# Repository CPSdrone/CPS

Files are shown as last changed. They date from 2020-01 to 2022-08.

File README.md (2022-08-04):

# CPS [Custom Printed Submarine]  CPSlogo

Is a project started by Filip Buława, Piotr Domanowski and Marcin Hnat. 
It is about creating a functional product of a innovative submarine, primarily with live streaming from camera in the drone. 
Project is based on 3D printing process, which allows developing various solutions for the form of a drone.

To learn more, find us on
* [Instagram](https://instagram.com/cpsdrone)
* [Facebook](https://facebook.com/cpsdrone)
* [YouTube](https://www.youtube.com/channel/UCqbdxbvG6cqnh_S_RcGnWWg)

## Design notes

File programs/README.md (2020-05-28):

# Welcome to our program storage.
## How to use our programs:

At the moment all of our programs use *Arduino IDE*, so 
1. make sure you installed this program
1. copy all of the libraries to the folder in the directory of your Arduino program, that is `Arduino/libraries`

Generally, the latest programs are the best.
Right now, if you want to use basic CPS code, use version 5.1.
For CPS M, probably `5.0/first_OSD_and_cleanup` is the best.

> Note: **Don't** look at the 1.0 - 2.0 so we won't feel ashamed.

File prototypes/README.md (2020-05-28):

#Welcome to our prototypes storage
Choose whether you want to explore **CPS** or **CPS M**

To learn more about each of these drones, visit our [Facebook](facebook.com/cpsdrone) or [YouTube](https://www.youtube.com/channel/UCqbdxbvG6cqnh_S_RcGnWWg) accounts
Shortly, **CPS** is:
* the basing drone for underwater exploration using only your live camera. More compact, less effort, fun build.
* the modular drone for more complex underwater exploration. 4 slots for any desired modules [like water sampler, manipulator, pH meter]. Still compact form, more effort, super fun especially with modules.

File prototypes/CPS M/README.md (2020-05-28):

# CPS M  prototypes
Along the way, we already had few prototypes of **CPS M**.

Generally, the latest prototype is the best.
In the folders you'll find models, list of materials and electronic diagrams.

Choose wisely

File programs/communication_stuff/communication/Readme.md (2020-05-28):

# Communication stuff
Here you can find code facilitating communication from outside to the drone and between individual components of the drone itself. For now, these are:
* raspberry pi 3
* Arduino mega 2560
the above are communicating by SPI. Communication with outside will be through WiFi.

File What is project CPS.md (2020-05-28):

CPSlogo
# CPS [Custom Printed Submarine]

 is an open-source project started by Filip Buława, Piotr Domanowski and Marcin Hnat. 
 It is about creating a functional product of a innovative submarine, primarily with live streaming from camera in the drone. 
 Project is based on 3D printing process, which allows developing various solutions for the form of a drone. 
Since the project is open-source, it will be easy for interested individuals to modify available models and programs and share with other people, who can eventually print it on their own 3D printers.

To learn more, find us on
* [Instagram](instagram.com/cpsdrone)
* [Facebook](facebook.com/cpsdrone)
* [YouTube](https://www.youtube.com/channel/UCqbdxbvG6cqnh_S_RcGnWWg)

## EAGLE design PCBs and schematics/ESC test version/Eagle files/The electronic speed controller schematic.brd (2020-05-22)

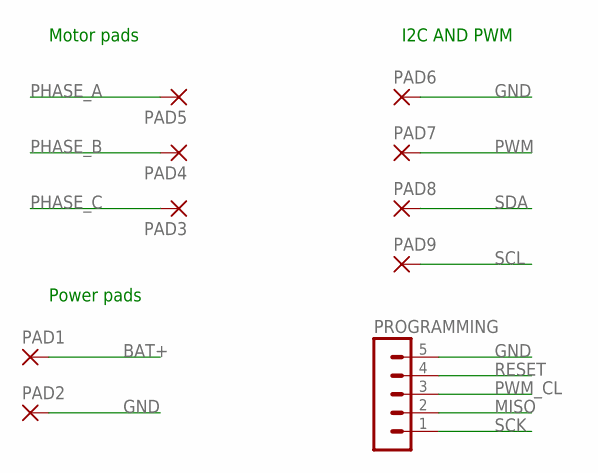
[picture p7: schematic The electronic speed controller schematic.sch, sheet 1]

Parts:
PAD1, PAD2, PAD3, PAD4, PAD5: SMD5; SMD2,54-5,08
PAD6, PAD7, PAD8, PAD9: SMD2; SMD1,27-2,54
PROGRAMMING: MA05-1

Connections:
BAT+: PAD1.1; also elsewhere on the board
GND: PAD2.1, PAD6.1, PROGRAMMING.5; also elsewhere on the board
MISO: PROGRAMMING.2; also elsewhere on the board
PHASE_A: PAD5.1; also elsewhere on the board
PHASE_B: PAD4.1; also elsewhere on the board
PHASE_C: PAD3.1; also elsewhere on the board
PWM: PAD7.1; also elsewhere on the board
PWM_CL: PROGRAMMING.3; also elsewhere on the board
RESET: PROGRAMMING.4; also elsewhere on the board
SCK: PROGRAMMING.1; also elsewhere on the board
SCL: PAD9.1; also elsewhere on the board
SDA: PAD8.1; also elsewhere on the board

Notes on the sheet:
Power pads
Motor pads
I2C AND PWM

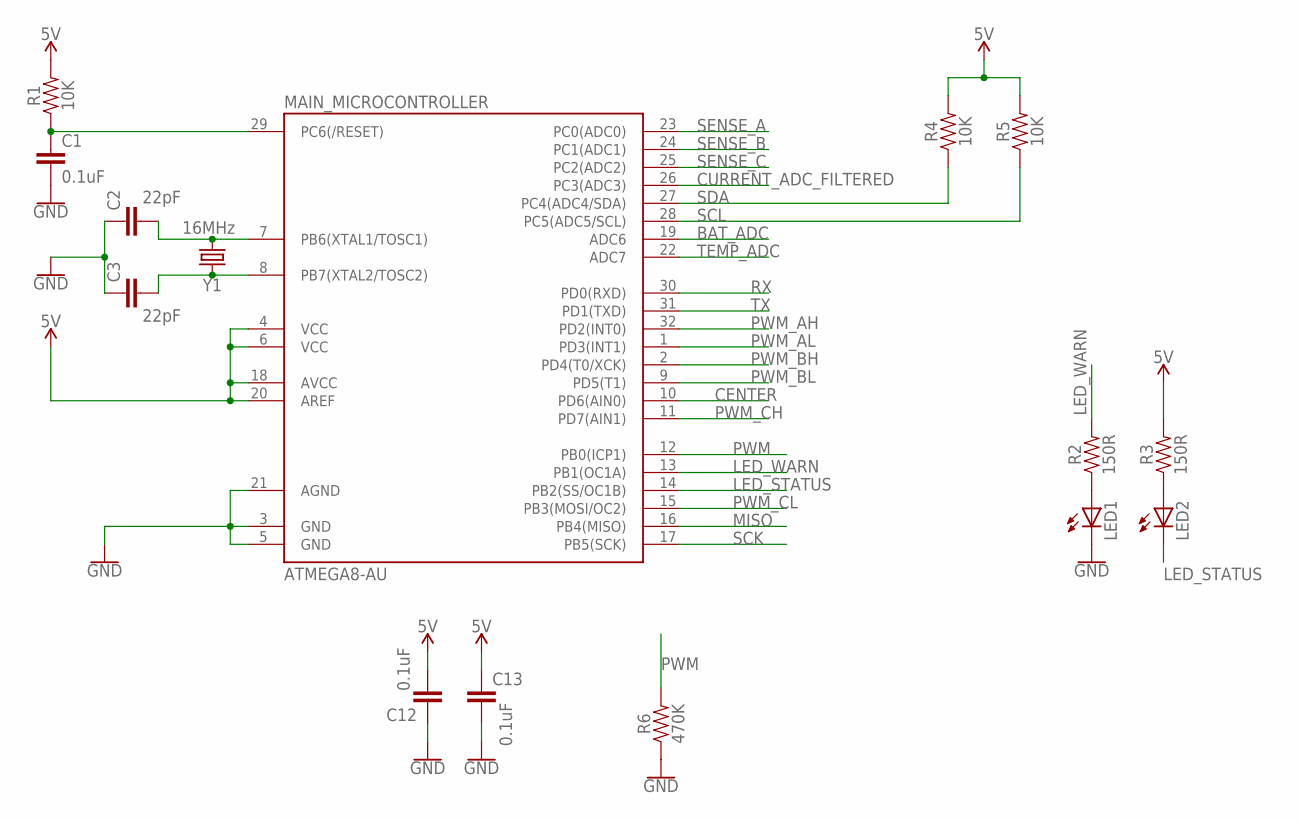
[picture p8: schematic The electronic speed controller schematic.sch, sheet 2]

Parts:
C1, C12, C13: 0.1uF; 0805
C2, C3: 22pF; 0805
LED1, LED2: LEDCHIPLED_0805; CHIPLED_0805
MAIN_MICROCONTROLLER: ATMEGA8-AU; TQFP32-08
R1, R4, R5: 10K; 0805
R2, R3: 150R; 0805
R6: 470K; 0805
Y1: 16MHz; CRYSTAL-SMD-5X3.2-4PAD

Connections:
5V: C12.2, C13.1, MAIN_MICROCONTROLLER.4 (VCC), MAIN_MICROCONTROLLER.6 (VCC), MAIN_MICROCONTROLLER.18 (AVCC), MAIN_MICROCONTROLLER.20 (AREF), R1.2, R3.2, R4.2, R5.2; also elsewhere on the board
BAT_ADC: MAIN_MICROCONTROLLER.19 (ADC6); also elsewhere on the board
CENTER: MAIN_MICROCONTROLLER.10 (PD6(AIN0)); also elsewhere on the board
CURRENT_ADC_FILTERED: MAIN_MICROCONTROLLER.26 (PC3(ADC3)); also elsewhere on the board
GND: C1.2, C2.1, C3.1, C12.1, C13.2, LED1.C, MAIN_MICROCONTROLLER.3 (GND), MAIN_MICROCONTROLLER.5 (GND), MAIN_MICROCONTROLLER.21 (AGND), R6.1; also elsewhere on the board
LED_STATUS: LED2.C, MAIN_MICROCONTROLLER.14 (PB2(SS/OC1B))
LED_WARN: MAIN_MICROCONTROLLER.13 (PB1(OC1A)), R2.2
MISO: MAIN_MICROCONTROLLER.16 (PB4(MISO)); also elsewhere on the board
unnamed: C2.2, MAIN_MICROCONTROLLER.7 (PB6(XTAL1/TOSC1)), Y1.3 (2)
unnamed: C3.2, MAIN_MICROCONTROLLER.8 (PB7(XTAL2/TOSC2)), Y1.1
unnamed: LED1.A, R2.1
unnamed: LED2.A, R3.1
PWM: MAIN_MICROCONTROLLER.12 (PB0(ICP1)), R6.2; also elsewhere on the board
PWM_AH: MAIN_MICROCONTROLLER.32 (PD2(INT0)); also elsewhere on the board
PWM_AL: MAIN_MICROCONTROLLER.1 (PD3(INT1)); also elsewhere on the board
PWM_BH: MAIN_MICROCONTROLLER.2 (PD4(T0/XCK)); also elsewhere on the board
PWM_BL: MAIN_MICROCONTROLLER.9 (PD5(T1)); also elsewhere on the board
PWM_CH: MAIN_MICROCONTROLLER.11 (PD7(AIN1)); also elsewhere on the board
PWM_CL: MAIN_MICROCONTROLLER.15 (PB3(MOSI/OC2)); also elsewhere on the board
RESET: C1.1, MAIN_MICROCONTROLLER.29 (PC6(/RESET)), R1.1; also elsewhere on the board
RX: MAIN_MICROCONTROLLER.30 (PD0(RXD))
SCK: MAIN_MICROCONTROLLER.17 (PB5(SCK)); also elsewhere on the board
SCL: MAIN_MICROCONTROLLER.28 (PC5(ADC5/SCL)), R5.1; also elsewhere on the board
SDA: MAIN_MICROCONTROLLER.27 (PC4(ADC4/SDA)), R4.1; also elsewhere on the board
SENSE_A: MAIN_MICROCONTROLLER.23 (PC0(ADC0)); also elsewhere on the board
SENSE_B: MAIN_MICROCONTROLLER.24 (PC1(ADC1)); also elsewhere on the board
SENSE_C: MAIN_MICROCONTROLLER.25 (PC2(ADC2)); also elsewhere on the board
TEMP_ADC: MAIN_MICROCONTROLLER.22 (ADC7); also elsewhere on the board
TX: MAIN_MICROCONTROLLER.31 (PD1(TXD))

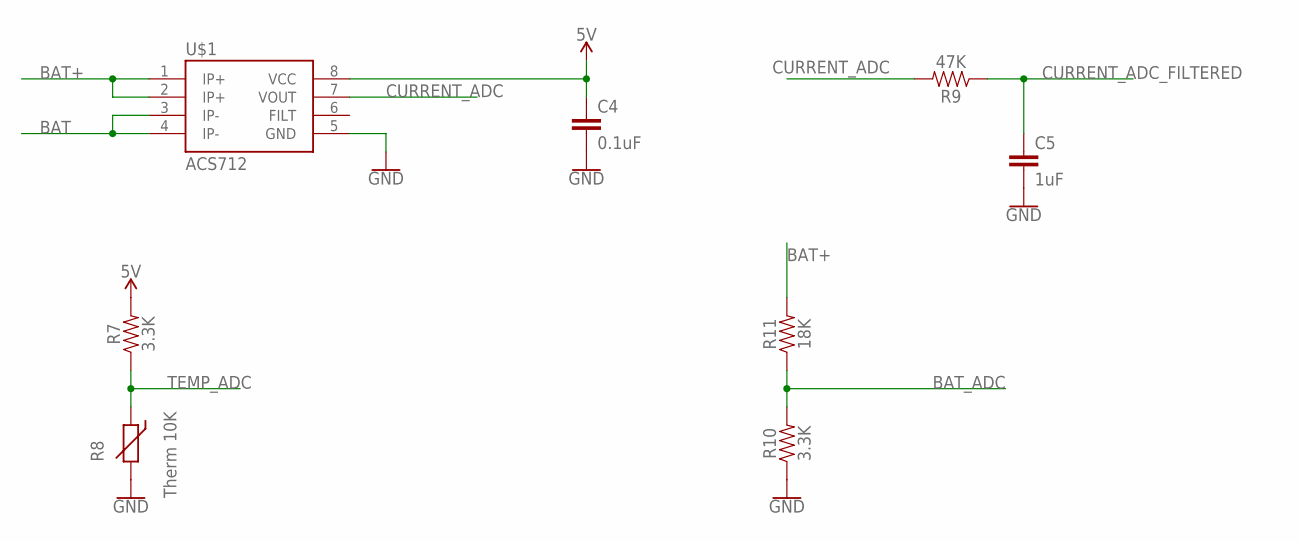
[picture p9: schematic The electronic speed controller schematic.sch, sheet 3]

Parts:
C4: 0.1uF; 0805
C5: 1uF; 1206
R7, R10: 3.3K; 0805
R8: Therm 10K; R-5
R9: 47K; 0805
R11: 18K; 0805
U$1: ACS712; SO08

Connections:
5V: C4.1, R7.2, U$1.8 (VCC); also elsewhere on the board
BAT: U$1.3 (IP-), U$1.4 (IP-); also elsewhere on the board
BAT+: R11.2, U$1.1 (IP+), U$1.2 (IP+); also elsewhere on the board
BAT_ADC: R10.2, R11.1; also elsewhere on the board
CURRENT_ADC: R9.2, U$1.7 (VOUT)
CURRENT_ADC_FILTERED: C5.1, R9.1; also elsewhere on the board
GND: C4.2, C5.2, R8.2, R10.1, U$1.5 (GND); also elsewhere on the board
TEMP_ADC: R7.1, R8.1; also elsewhere on the board

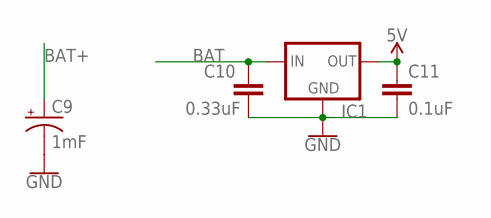
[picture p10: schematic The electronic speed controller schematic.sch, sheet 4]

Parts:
C9: 1mF; CPOL-RADIAL-5MM-10MM
C10: 0.33uF; 0805
C11: 0.1uF; 0805
IC1: 78LXX-SOT89; SOT89

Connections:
5V: C11.1, IC1.1 (OUT); also elsewhere on the board
BAT: C10.1, IC1.3 (IN); also elsewhere on the board
BAT+: C9.+; also elsewhere on the board
GND: C9.-, C10.2, C11.2, IC1.2 (GND); also elsewhere on the board

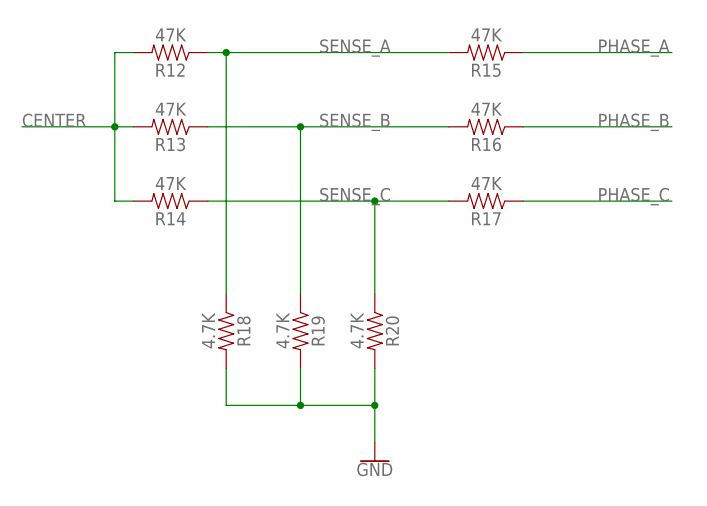
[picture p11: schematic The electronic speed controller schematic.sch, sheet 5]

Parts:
R12, R13, R14, R15, R16, R17: 47K; 0805
R18, R19, R20: 4.7K; 0805

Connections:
CENTER: R12.2, R13.2, R14.2; also elsewhere on the board
GND: R18.2, R19.2, R20.2; also elsewhere on the board
PHASE_A: R15.1; also elsewhere on the board
PHASE_B: R16.1; also elsewhere on the board
PHASE_C: R17.1; also elsewhere on the board
SENSE_A: R12.1, R15.2, R18.1; also elsewhere on the board
SENSE_B: R13.1, R16.2, R19.1; also elsewhere on the board
SENSE_C: R14.1, R17.2, R20.1; also elsewhere on the board

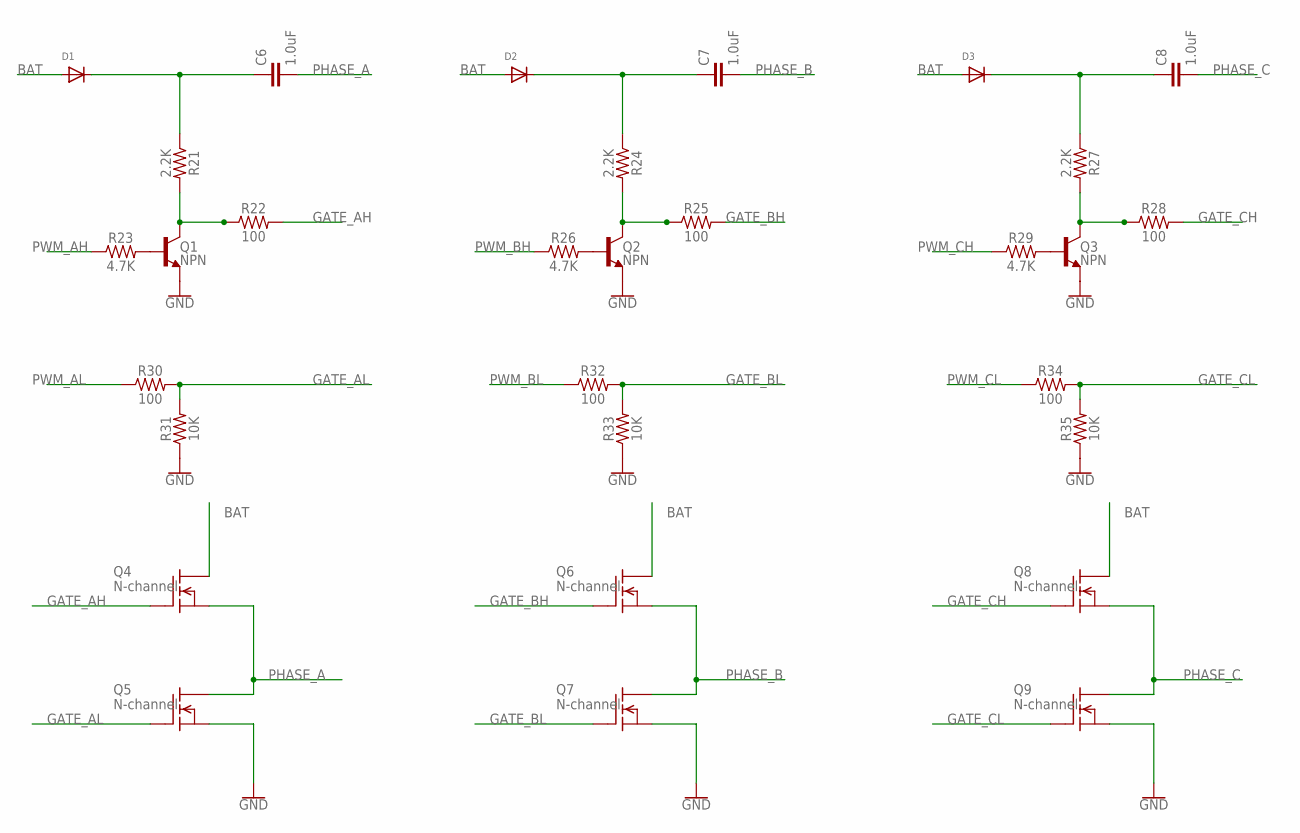
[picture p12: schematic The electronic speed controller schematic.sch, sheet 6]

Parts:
C6, C7, C8: 1.0uF; 1206
D1, D2, D3: DIODESOD-123; SOD-123
Q1, Q2, Q3: NPN; SOT23-3
Q4, Q5, Q6, Q7, Q8, Q9: N-channel; TO252
R21, R24, R27: 2.2K; 0805
R22, R25, R28, R30, R32, R34: 100; 0805
R23, R26, R29: 4.7K; 0805
R31, R33, R35: 10K; 0805

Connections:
BAT: D1.A, D2.A, D3.A, Q4.2 (D), Q6.2 (D), Q8.2 (D); also elsewhere on the board
GATE_AH: Q4.1 (G), R22.2
GATE_AL: Q5.1 (G), R30.2, R31.2
GATE_BH: Q6.1 (G), R25.2
GATE_BL: Q7.1 (G), R32.2, R33.2
GATE_CH: Q8.1 (G), R28.2
GATE_CL: Q9.1 (G), R34.2, R35.2
GND: Q1.2 (E), Q2.2 (E), Q3.2 (E), Q5.3 (S), Q7.3 (S), Q9.3 (S), R31.1, R33.1, R35.1; also elsewhere on the board
unnamed: C6.1, D1.C, R21.1
unnamed: Q1.3 (C), R21.2, R22.1
unnamed: Q1.1 (B), R23.2
unnamed: C7.1, D2.C, R24.1
unnamed: Q2.3 (C), R24.2, R25.1
unnamed: Q2.1 (B), R26.2
unnamed: C8.1, D3.C, R27.1
unnamed: Q3.3 (C), R27.2, R28.1
unnamed: Q3.1 (B), R29.2
PHASE_A: C6.2, Q4.3 (S), Q5.2 (D); also elsewhere on the board
PHASE_B: C7.2, Q6.3 (S), Q7.2 (D); also elsewhere on the board
PHASE_C: C8.2, Q8.3 (S), Q9.2 (D); also elsewhere on the board
PWM_AH: R23.1; also elsewhere on the board
PWM_AL: R30.1; also elsewhere on the board
PWM_BH: R26.1; also elsewhere on the board
PWM_BL: R32.1; also elsewhere on the board
PWM_CH: R29.1; also elsewhere on the board
PWM_CL: R34.1; also elsewhere on the board

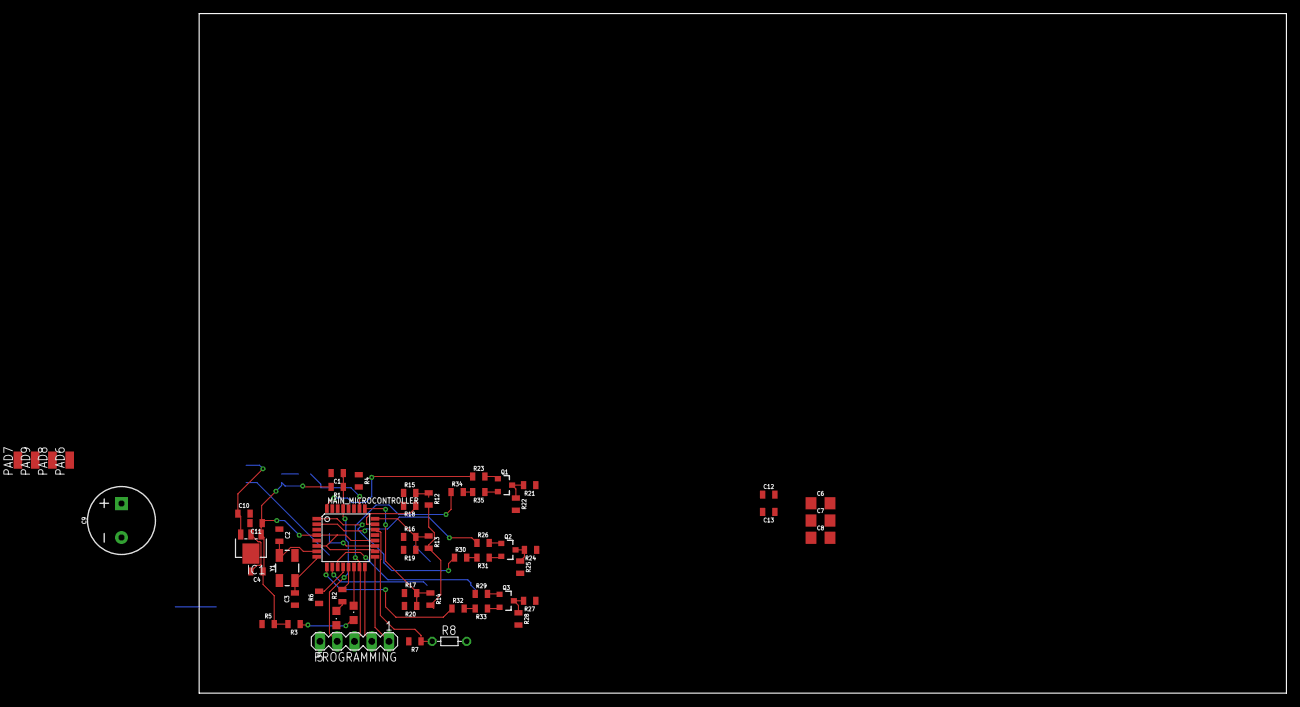
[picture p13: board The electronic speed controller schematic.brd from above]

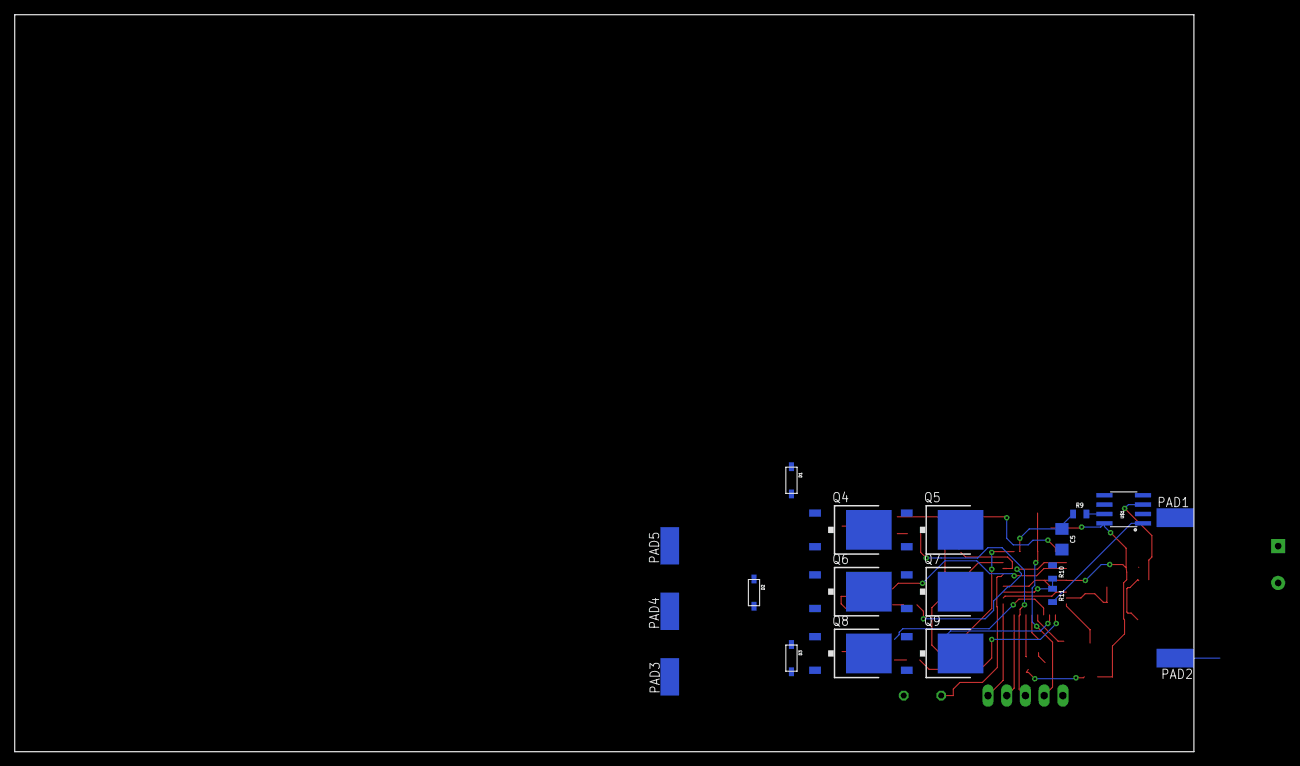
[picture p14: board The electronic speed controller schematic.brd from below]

Board: 2 copper layers, 160.0 x 100.0 mm, 76 parts (19 on the bottom side), 48 nets.

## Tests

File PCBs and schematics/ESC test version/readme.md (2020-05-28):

# ESC test version
This is a work in progress version of our own electronic speed controller for controlling **BLDC** motors featuring **I2C** communication, current and temperature sensors. This is version used only for creating the program and not the final **ESC**!

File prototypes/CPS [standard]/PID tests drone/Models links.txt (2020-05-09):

Electronics case: 
a360.co/3ceX0d0

Battery case:
a360.co/2zsh5yc

motors mounts:
link very soon

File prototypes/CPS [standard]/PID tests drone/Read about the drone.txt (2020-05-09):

PID test drone [deskodron PID]

This prototype was created to test our new PID system for steering, mainly self leveling. It is our first prototype in which we had 5 motors:
motor A, left front [up, down]
motor B, right front [up, down]
motor C, middle back [up, down]
motor L, left [forward, backward]
motor R, right [forward, backward]

With these motors it is possible to change yaw, pitch, roll as well as swim in x and z axis.

It consists mainly of 2 big 3D printed boxes and a wooden frame.

More about the prototype, assembly manual and other cool stuff will be added soon.

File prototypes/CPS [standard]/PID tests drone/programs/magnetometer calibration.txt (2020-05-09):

HARD -> shift from origin
SOFT -> stretch

	manual

HARD IRON OFFSET
for every axis: 
(parallel to north)
reading + reading opposite way = 2 mag offset
then substract calculated offset from readings on given axis

Raspberry Pi maybe has some functionality with LSM9D01

	automatic

HARD
automating manual method with live min and max values, then live calc offsets

int mx, my, mz;

int mx_min, my_min, mz_min;
int mx_max, my_max, mz_max;
int mx_offset, my_offset, mz_offset;

int mx_calibrated, my_calibrated, mz_calibrated;

// get min/max values by taking readings
// from magnetometer of your choice

mx_offset = (mx_min + mx_max)/2;
my_offset = (my_min + my_max)/2;
mz_offset = (mz_min + mz_max)/2;

mx_calibrated = mx - mx_offset;
my_calibrated = my - my_offset;
mz_calibrated = mz - mz_offset;

SOFT

int mx_scale, my_scale, mz_scale;

mx_scale = (mx_max - mx_min)/2;
my_scale = (my_max - my_min)/2;
mz_scale = (mz_max - mz_min)/2;

float avg_scale = (mx_scale + my_scale + mz_scale)/3;

mx_calibrated = avg_scale/(mx - mx_offset);
my_calibrated = avg_scale/(my - my_offset);
mz_calibrated = avg_scale/(mz - mz_offset);

OTHER SOFT

avg_delta_x = (max(x) - min(x)) / 2
avg_delta_y = (max(y) - min(y)) / 2
avg_delta_z = (max(z) - min(z)) / 2

avg_delta = (avg_delta_x + avg_delta_y + avg_delta_z) / 3

scale_x = avg_delta / avg_delta_x                       // this is different
scale_y = avg_delta / avg_delta_y
scale_z = avg_delta / avg_delta_z

corrected_x = (sensor_x - offset_x) * scale_x
corrected_y = (sensor_y - offset_y) * scale_y
corrected_z = (sensor_z - offset_z) * scale_z

using Arduino code for different IMU somehow (a lot of work)

visualisation of the spheres - some advanced, better claib

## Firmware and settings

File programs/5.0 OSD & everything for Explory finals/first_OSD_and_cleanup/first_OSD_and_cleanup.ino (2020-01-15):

/////////////////////////////////PPM READING PRE SETUP/////////////////////////////////

#define RECEIVE_PIN 2
#define CHANNEL_AMOUNT 8
#define DETECTION_SPACE 2500
#define METHOD RISING

int ch[CHANNEL_AMOUNT + 1];

/////////////////////////////////STEERING PRE SETUP/////////////////////////////////

#include <Servo.h>;
Servo motorupdown;
Servo motorside;
Servo motorleft;
Servo motorright;

int valLUP;
int valRUP;
int valLLR;
int valRLR;


/////////////////////////////////MODULES PRE SETUP/////////////////////////////////
Servo motorcamera;
Servo motorlapa;
Servo motorprobe;

float valbat;

float valup;
float valright;
float valdown;
float valleft;

float voltup;
float voltright;
float voltdown;
float voltleft;

int varCAM;
int conCAM = 90;
int varLAP;
int conLAP = 90;
int varPRO;
int conPRO = 180;

int lapapin;
int probepin;


int pHpin;
float calibration = 22.25;
int pHreading = 0;
unsigned long int avgValue;
float b;
int buf[10],temper;

/////////////////////////////////OSD PRE SETUP/////////////////////////////////

#include <SPI.h>
#include <max7456.h>
Max7456 osd;

unsigned long counter = 0;

float volt;
int clearval = 1;

/////////////////////////////////IMU PRE SETUP/////////////////////////////////

#include <Adafruit_LSM9DS1.h>
#include <Adafruit_Sensor.h>  // not used in this demo but required!

Adafruit_LSM9DS1 lsm = Adafruit_LSM9DS1();

#define LSM9DS1_SCK A5
#define LSM9DS1_MISO 12
#define LSM9DS1_MOSI A4
#define LSM9DS1_XGCS 6
#define LSM9DS1_MCS 5


/////////////////////////////////THERMOMETER PRE SETUP/////////////////////////////////

#include <OneWire.h>
#include <DallasTemperature.h>

#define ONE_WIRE_BUS 5
#define TEMPERATURE_PRECISION 12

OneWire oneWire(ONE_WIRE_BUS);
DallasTemperature sensors(&oneWire);

int numberOfDevices;
DeviceAddress tempDeviceAddress;

DeviceAddress deviceAddress;


///////////////////////////////////////LED/////////////////////////////////////////

int ledPinGreen = 9;
int ledPinRed = 11;

int ledlights = 4;
int vallights;
int valBlink;










void OSDstart() {
  SPI.begin();
  
    osd.init(10);
    osd.setDisplayOffsets(35,0);
    osd.activateOSD();
}




void IMUsetup(){
      while (!Serial) {
          delay(1); // will pause Zero, Leonardo, etc until serial console opens
        }
        
        Serial.println("LSM9DS1 data read demo");
        
        // Try to initialise and warn if we couldn't detect the chip
        if (!lsm.begin())
        {
          Serial.println("Oops ... unable to initialize the LSM9DS1. Check your wiring!");
          while (1);
        }
        Serial.println("Found LSM9DS1 9DOF");
      
        // helper to just set the default scaling we want, see above!
        setupSensor();
}
void setupSensor()
    {
      // 1.) Set the accelerometer range
      lsm.setupAccel(lsm.LSM9DS1_ACCELRANGE_2G);
      //lsm.setupAccel(lsm.LSM9DS1_ACCELRANGE_4G);
      //lsm.setupAccel(lsm.LSM9DS1_ACCELRANGE_8G);
      //lsm.setupAccel(lsm.LSM9DS1_ACCELRANGE_16G);
      
      // 2.) Set the magnetometer sensitivity
      lsm.setupMag(lsm.LSM9DS1_MAGGAIN_4GAUSS);
      //lsm.setupMag(lsm.LSM9DS1_MAGGAIN_8GAUSS);
      //lsm.setupMag(lsm.LSM9DS1_MAGGAIN_12GAUSS);
      //lsm.setupMag(lsm.LSM9DS1_MAGGAIN_16GAUSS);
    
      // 3.) Setup the gyroscope
      //lsm.setupGyro(lsm.LSM9DS1_GYROSCALE_245DPS);
      lsm.setupGyro(lsm.LSM9DS1_GYROSCALE_500DPS);
      //lsm.setupGyro(lsm.LSM9DS1_GYROSCALE_2000DPS);
    }






void thermometerSetup(void){
  Serial.println("Dallas Temperature IC Control Library Demo");
  sensors.begin();
  
  numberOfDevices = sensors.getDeviceCount();
  Serial.print("Locating devices...");
  Serial.print("Found ");
  Serial.print(numberOfDevices, DEC);
  Serial.println(" devices.");
  
  Serial.print("Parasite power is: "); 
  if (sensors.isParasitePowerMode()) Serial.println("ON");
  else Serial.println("OFF");
  
  for(int i=0;i<numberOfDevices; i++)
  {
    // Search the wire for address
    if(sensors.getAddress(tempDeviceAddress, i)){
      Serial.print("Found device ");
      Serial.print(i, DEC);
      Serial.print(" with address: ");
      printAddress(tempDeviceAddress);
      Serial.println();
    
      Serial.print("Setting resolution to ");
      Serial.println(TEMPERATURE_PRECISION, DEC);
    
      // set the resolution to TEMPERATURE_PRECISION bit (Each Dallas/Maxim device is capable of several different resolutions)
      sensors.setResolution(tempDeviceAddress, TEMPERATURE_PRECISION);
    
      Serial.print("Resolution actually set to: ");
      Serial.print(sensors.getResolution(tempDeviceAddress), DEC); 
      Serial.println();
    }else{
      Serial.print("Found ghost device at ");
      Serial.print(i, DEC);
      Serial.print(" but could not detect address. Check power and cabling");
    }
  }
}




void ledStart(){
pinMode(ledPinGreen, OUTPUT);
pinMode(ledPinRed, OUTPUT);
pinMode(ledlights, OUTPUT);
  for (int fadeValue = 0 ; fadeValue <= 255; fadeValue += 1) {
    analogWrite(ledPinGreen, fadeValue);
    analogWrite(ledPinRed, fadeValue);
    analogWrite(ledlights, fadeValue);
    delay(10);
  }
delay(100);
digitalWrite(ledPinRed, LOW);
digitalWrite(ledPinGreen, HIGH);
delay(100);
digitalWrite(ledPinRed, HIGH);
digitalWrite(ledPinGreen, LOW);
delay(100);
digitalWrite(ledPinRed, LOW);
digitalWrite(ledPinGreen, HIGH);
delay(100);
digitalWrite(ledPinRed, HIGH);
digitalWrite(ledPinGreen, LOW);
delay(100);
digitalWrite(ledPinRed, LOW);
digitalWrite(ledPinGreen, HIGH);
delay(100);
digitalWrite(ledPinRed, HIGH);
digitalWrite(ledPinGreen, LOW);
delay(100);
digitalWrite(ledPinGreen, HIGH);
}









void setup() {
Serial.begin(115200);
pinMode(RECEIVE_PIN, INPUT_PULLUP);
attachInterrupt(digitalPinToInterrupt(RECEIVE_PIN), ppm_interrupt, METHOD);

                                                                                  ///////////////////////////////
//OSDstart();
//IMUsetup();
//thermometerSetup();
ledStart();
}










void loop(){
ppm_write();

//Serial.print(ch[1]);Serial.print("\t");
//Serial.print(ch[2]);Serial.print("\t");
//Serial.print(ch[3]);Serial.print("\t");
//Serial.print(ch[4]);Serial.print("\t");
//Serial.print(ch[5]);Serial.print("\t");
//Serial.print(ch[6]);Serial.print("\t");
//Serial.print(ch[7]);Serial.print("\t");
//Serial.print(ch[8]);Serial.print("\n");
                                                                     /////////////                              //////////
counter = millis()/1000;
                                                                     
analogreading();
IMUrun();
steer();
temperatureGet();
ledRun();
OSDrun();

valcheck();
}










void ppm_write()
{
static unsigned long int t;
if (millis() - t < 100)
return 0;
for (byte i = 0; i < CHANNEL_AMOUNT + 1; i++)
{
Serial.print(ch[i]);
Serial.print("\t");
}
Serial.print("\n");
t = millis();
}

void ppm_interrupt()
{
static byte i;
static unsigned long int t_old;
unsigned long int t = micros(); //store time value a when pin value falling/rising
unsigned long int dt = t - t_old; //calculating time inbetween two peaks
t_old = t;

if ((dt > DETECTION_SPACE) || (i > CHANNEL_AMOUNT))
{
i = 0;
}
ch[i++] = dt;
}












void analogreading(){
  valbat=analogRead(A2);
  
  valup=analogRead(A4);
  valright=analogRead(A6);
  valdown=analogRead(A5);
  valleft=analogRead(A7);

  volt = valbat * 5.0/1023;
  
  voltup = valup * 5.0/1023;  
  voltright = valright * 5.0/1023;
  voltdown = valdown * 5.0/1023;
  voltleft = valleft * 5.0/1023;

//  Serial.print("volt ");
//  Serial.print(volt);
//  Serial.print(" voltup ");
//  Serial.print(voltup);
//  Serial.print(" voltright ");
//  Serial.print(voltright);
//  Serial.print(" voltdown ");
//  Serial.print(voltdown);
//  Serial.print(" voltleft ");
//  Serial.print(probepin);
//  Serial.println(voltleft);
}





void IMUrun(){
        lsm.read();

      sensors_event_t a, m, g, temp;
    
      lsm.getEvent(&a, &m, &g, &temp); 
    
      Serial.print("Accel X: "); Serial.print(a.acceleration.x); Serial.print(" m/s^2");
      Serial.print("\tY: "); Serial.print(a.acceleration.y);     Serial.print(" m/s^2 ");
      Serial.print("\tZ: "); Serial.print(a.acceleration.z);     Serial.println(" m/s^2 ");
    
      Serial.print("Mag X: "); Serial.print(m.magnetic.x);   Serial.print(" gauss");
      Serial.print("\tY: "); Serial.print(m.magnetic.y);     Serial.print(" gauss");
      Serial.print("\tZ: "); Serial.print(m.magnetic.z);     Serial.println(" gauss");
    
      Serial.print("Gyro X: "); Serial.print(g.gyro.x);   Serial.print(" dps");
      Serial.print("\tY: "); Serial.print(g.gyro.y);      Serial.print(" dps");
      Serial.print("\tZ: "); Serial.print(g.gyro.z);      Serial.println(" dps");

    delay(200);
}


void steer(){
if(voltup>3.3 && voltup<3.5) lapapin = 6;
else if (voltup>4.45 && voltup<4.65) probepin = 6;
else if (voltup>2.4 && voltup<2.6){ 
  pHpin = A10;
  pHget();
}

if(voltright>3.3 && voltright<3.5) lapapin = 10;
else if (voltright>4.45 && voltright<4.65) probepin = 10;
else if (voltright>2.4 && voltright<2.6){
  pHpin = A12;
  pHget();
}

if(voltdown>3.3 && voltdown<3.5) lapapin = 8;
else if (voltdown>4.45 && voltdown<4.65) probepin = 8;
else if (voltdown>2.4 && voltdown<2.6){
  pHpin = A11;
  pHget();
}

if(voltleft>3.3 && voltleft<3.5) lapapin = 12;
else if (voltleft>4.45 && voltleft<4.65) probepin = 12;
else if (voltleft>2.4 && voltleft<2.6){
  pHpin = A13;
  pHget();
}

  
              motorupdown.attach(28,1000,2000);
              motorside.attach(30,1000,2000);
              motorleft.attach(26,1000,2000);
              motorright.attach(24,1000,2000);
              motorcamera.attach(14,500,2500);
              motorlapa.attach(lapapin,1000,2000);
              motorprobe.attach(probepin,1000,2000);
              
              valLLR = map(ch[4], 1000, 2000, 0, 180);
              valRUP = map(ch[2], 1000, 2000, 0, 180);
              valLUP = map(ch[3], 1000, 2000, 0, 180);
              valRLR = map(ch[1], 1000, 2000, 0, 180);
              
              varCAM = map(ch[5], 1000, 2000, 0, 180);
              varLAP = map(ch[6], 1000, 2000, 0, 180);
              varPRO = map(ch[7], 1000, 2000, 0, 180);
                     
      motorupdown.write(180-valLUP+10);
      motorside.write(valRLR);
      motorleft.write(valRUP+(valLLR-90));
      motorright.write(valRUP-(valLLR-90));
      
      conCAM = constrain(conCAM,0, 180);
      conCAM=conCAM+(90-varCAM)/8;
      motorcamera.write(conCAM);
      
      motorlapa.write(varLAP);


//vallights = map(ch[10], 1000, 2000, 0, 180);
//Serial.print(vallights);

      

      conPRO = constrain(conPRO,0, 180);
      conPRO=conPRO+(90-varPRO)/2;
      motorprobe.write(conPRO);
}




void pHget(){
 
 for(int i=0;i<10;i++) 
 { 
 buf[i]=analogRead(pHpin);
 delay(30);
 }
 for(int i=0;i<9;i++)
 {
 for(int j=i+1;j<10;j++)
 {
 if(buf[i]>buf[j])
 {
 temper=buf[i];
 buf[i]=buf[j];
 buf[j]=temper;
 }
 }
 }
 avgValue=0;
 for(int i=2;i<8;i++)
 avgValue+=buf[i];
 float pHVol=(float)avgValue*5.0/1024/6;
 float phValue = -5.70 * pHVol + calibration;
 Serial.print("sensor = ");
 Serial.println(phValue);
 
 delay(1);
}















void temperatureGet(){
// call sensors.requestTemperatures() to issue a global temperature 
  // request to all devices on the bus
  Serial.print("Requesting temperatures...");
  sensors.requestTemperatures(); // Send the command to get temperatures
  Serial.println("DONE");
  
  
  // Loop through each device, print out temperature data
  for(int i=0;i<numberOfDevices; i++)
  {
    // Search the wire for address
    if(sensors.getAddress(tempDeviceAddress, i))
  {
    // Output the device ID
    Serial.print("Temperature for device: ");
    Serial.println(i,DEC);
    
    // It responds almost immediately. Let's print out the data
    //printTemperature(tempDeviceAddress); // Use a simple function to print out the data
    float tempC = sensors.getTempC(deviceAddress);
  osd.print(tempC, 23, 3, 2, 1, false, true);
  osd.printMax7456Char(0xD0, 27, 3);
  Serial.print("Temp C: ");
  Serial.print(tempC);
  } 
  //else ghost device! Check your power requirements and cabling
  
  }
}





void printTemperature(DeviceAddress deviceAddress) 
{
  // method 1 - slower
  //Serial.print("Temp C: ");
  //Serial.print(sensors.getTempC(deviceAddress));
  //Serial.print(" Temp F: ");
  //Serial.print(sensors.getTempF(deviceAddress)); // Makes a second call to getTempC and then converts to Fahrenheit

  // method 2 - faster
  float tempC = sensors.getTempC(deviceAddress);
  osd.print(tempC, 23, 3, 2, 1, false, true);
  osd.printMax7456Char(0xD0, 27, 3);
  Serial.print("Temp C: ");
  Serial.print(tempC);
  Serial.print(" Temp F: ");
  Serial.println(DallasTemperature::toFahrenheit(tempC)); // Converts tempC to Fahrenheit
}





void printAddress(DeviceAddress deviceAddress)
{
  for (uint8_t i = 0; i < 8; i++)
  {
    if (deviceAddress[i] < 16) Serial.print("0");
    Serial.print(deviceAddress[i], HEX);
  }
}






void ledRun(){
    vallights = map(ch[7], 1000, 2000, 0, 180);
      //valBlink = map(ch[8], 1000, 2000, 0, 180);
      
    Serial.println(vallights);

  if(vallights=2) analogWrite(ledlights, 980);
  else if(vallights=1) analogWrite(ledlights, 490);
  else if(vallights=0) analogWrite(ledlights, 0);

  if((valBlink=0)&&(micros()%0)) digitalWrite(ledlights, LOW);

  if(volt>=10.5){
  digitalWrite(ledPinGreen, HIGH);
  digitalWrite(ledPinRed, HIGH);
  }else if(volt<10.5){
    if(counter%10){
    digitalWrite(ledPinGreen, LOW);
    digitalWrite(ledPinRed, LOW);
    }
  }else if(volt<10.2){
    if(counter%4){
    digitalWrite(ledPinGreen, LOW);
    digitalWrite(ledPinRed, LOW);
    }
  }

  
}





void OSDrun(){


//if(clearval>1){

/////TEST///////
//volt = 12.6 - (millis()/1000);
////////////////


if(volt>11.7){
  osd.printMax7456Char(0x90,0,1);
  osd.printMax7456Char(0x00,1,1);
  osd.printMax7456Char(0x00,2,1);
  osd.printMax7456Char(0x00,3,1);
}else if(volt>11.25){
  osd.printMax7456Char(0x91,0,1);
  osd.printMax7456Char(0x00,1,1);
  osd.printMax7456Char(0x00,2,1);
  osd.printMax7456Char(0x00,3,1);
}else if(volt>10.8){
  osd.printMax7456Char(0x92,0,1);
  osd.printMax7456Char(0x00,1,1);
  osd.printMax7456Char(0x00,2,1);
  osd.printMax7456Char(0x00,3,1);
}else if(volt>10.5){
  osd.printMax7456Char(0x93,0,1);
  osd.printMax7456Char(0x00,1,1);
  osd.printMax7456Char(0x00,2,1);
  osd.printMax7456Char(0x00,3,1);
}else if(volt>10.35){
  osd.printMax7456Char(0x94,0,1);
  osd.printMax7456Char(0x00,1,1);
  osd.printMax7456Char(0x00,2,1);
  osd.printMax7456Char(0x00,3,1);
}else if(volt>10.05){
  osd.printMax7456Char(0x95,0,1);
  osd.printMax7456Char(0x00,1,1);
  osd.printMax7456Char(0x00,2,1);
  osd.printMax7456Char(0x00,3,1);
}else if(volt>9){
  osd.printMax7456Char(0x96,0,1);
  osd.printMax7456Char(0x00,1,1);
  osd.printMax7456Char(0x00,2,1);
  osd.printMax7456Char(0x00,3,1);
}else if(volt<=9){
  osd.print("dead",0,1);
}


//osd.print("throt",0,15);
//osd.print(max((valRUP+(valLLR-90)),(valRUP-(valLLR-90))),16,1,1,0,false,true);

//osd.print("temp", 24, 3);
//osd.print(tempC, 23, 3, 2, 1, false, true)
//in the temperature function

osd.print(int(counter%60), 15, 1, 2, 0, false, true);
osd.print(":", 14, 1, false, true);
osd.print(int(counter/60), 12, 1, 2, 0, false, true);

osd.printMax7456Char(0xF5, 22, 1);
osd.printMax7456Char(0xF6, 23, 1);
osd.print(analogRead(ledlights), 24, 1, 2, 1, false, true);

if((voltup>3.3)&&(voltup<3.5)||(voltright>3.3)&&(voltright<3.5)||(voltdown>3.3)&&(voltdown<3.5)||(voltleft>3.3)&&(voltleft<3.5)){
  osd.print("arm", 21, 13);
  osd.print(conLAP, 25, 13, 3, 0, false, true);
}else{
  for(int f = 21; f <= 27; f++){
  osd.printMax7456Char(0x00,f,13);
  }
}























if((voltup>4.45)&&(voltup<4.65)||(voltright>4.45)&&(voltright<4.65)||(voltdown>4.45)&&(voltdown<4.65)||(voltleft>4.45)&&(voltleft<4.65)){
  osd.print("pro", 21, 11);
  osd.print(conPRO, 25, 11, 3, 0, false, true);
}else{
  for(int f = 21; f <= 27; f++){
  osd.printMax7456Char(0x00,f,11);
  }
}

if((voltup>2.4)&&(voltup<2.6)||(voltright>2.4)&&(voltright<2.6)||(voltdown>2.4)&&(voltdown<2.6)||(voltleft>2.4)&&(voltleft<2.6)){
  osd.print("pH", 21, 12);
  osd.print(pHpin, 24, 12, 2, 1, false, true);
}else{
  for(int f = 21; f <= 27; f++){//                                idk if f can be for all
  osd.printMax7456Char(0x00,f,12);
  }
}
//if(clearval>1){
//  for(int a=0;a<=26;a++){
//    for(int b=1;b<=15;b++){
//      osd.printMax7456Char(0x00,a,b);
//    }
//  }
//  delay(1000);
//}
//}else if(clearval<1){
//  osd.clearScreen();
//}
}















void valcheck(){
    Serial.print(" left : ");
    Serial.print(valRUP+(valLLR-90));
    Serial.print(" right : ");
    Serial.print(valRUP-(valLLR-90));
    Serial.print(" front : ");
    Serial.print(180-valLUP);
    Serial.print(" side : ");
    Serial.print(valRLR);
    Serial.print(" camera : ");
    Serial.print(conCAM);
    Serial.print(" lapa : ");
    Serial.print(varLAP);
    Serial.print(" probe : ");
    Serial.println(conPRO);
//
//  delay(3000);
}

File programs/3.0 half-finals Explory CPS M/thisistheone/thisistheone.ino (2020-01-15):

unsigned long int ft, lt, x, tfail;
int ch, chx[9][13];
const int idx   = 10;
const int total = 11;
const int val   = 12; //End of specifying the integers for ppm signal reading 

int valLUP;
int valRUP;
int valLLR;
int valCAM;
int varDOL;
int varGOR;
int varPRA;
int varLEW;
int conDOL = 90;
int conGOR = 90;
int conPRA = 90;
int conLEW = 90;


#include <Servo.h>;
Servo motorfront;
Servo motorleft;
Servo motorright;
Servo motorcamera;
Servo motorlapa;
Servo motordol;
Servo motorgora;
Servo motorprawo;
Servo motorlewo;


void setup() {
  Serial.begin(9600);
  
  ft=0; lt=0; x=0; tfail=0; ch=0;
for (int i=0; i<9; i++) {
for (int j=0; j<13; j++) {
      chx[i][j]=0;
    }
  }
pinMode(2, INPUT_PULLUP);
attachInterrupt(digitalPinToInterrupt(2), decodePPM, FALLING);
}




void decodePPM() {  
  lt    = micros();
  tfail = millis();
  x     = lt-ft;
  ft    = lt;
if (x>3000) {
    ch          = 0;
    chx[0][val] = x;
  } else {
    ch+=1;
int indx       = chx[ch][idx];
    chx[ch][total] = chx[ch][total] - chx[ch][indx];
    chx[ch][indx]  = x;
    chx[ch][total] = chx[ch][total] + chx[ch][indx];
    chx[ch][idx]   = chx[ch][idx] + 1;
if (chx[ch][idx]>9) {
      chx[ch][idx] = 0;
    }
    chx[ch][val] = chx[ch][total]/10;
  }
}                                              //end of code for ppm reading





void loop() {
 if ((millis()-tfail)>500) {
    Serial.println("Disconnect");
  } else {
    //Serial.print(chx[0][val]);Serial.print("\t");
    //Serial.print(chx[1][val]);Serial.print("\t");
    //Serial.print(chx[2][val]);Serial.print("\t");
    //Serial.print(chx[3][val]);Serial.print("\t");
    //Serial.print(chx[4][val]);Serial.print("\t"); 
    //Serial.print(chx[5][val]);Serial.print("\t");
    //Serial.print(chx[6][val]);Serial.print("\t");
    //Serial.print(chx[7][val]);Serial.print("\t");
    //Serial.println(chx[8][val]);Serial.print("\t");
   // delay(6000);
 }
motorfront.attach(10,1000,2000);                 //beggining of the code for controling motors 
motorleft.attach(8,1000,2000) ;
motorright.attach(7,1000,2000);
motorcamera.attach(11,500,2500);
motordol.attach(9,500,2500);
motorgora.attach(6,500,2500);
motorprawo.attach(5,500,2500);
motorlewo.attach(3,500,2500);
//valLUP = chx[3][val]; //LUP - left up down,   RUP - right up down,   LLR - Left left right,   RLR - Right left right 
//valRUP = chx[2][val];
//valLLR = chx[4][val]; 

valLLR = map(chx[4][val], 1000, 2000, 0, 180);
valRUP = map(chx[2][val], 1000, 2000, 0, 180);
valLUP = map(chx[3][val], 1000, 2000, 0, 180);
valCAM = map(chx[5][val], 1000, 2000, 0, 180);
varDOL = map(chx[6][val], 1000, 2000, 0, 180);
varGOR = map(chx[7][val], 1000, 2000, 0, 180);
varPRA = map(chx[8][val], 1000, 2000, 0, 180);
varLEW = map(chx[9][val], 1000, 2000, 0, 180);

motorfront.write(180-valLUP);
motorcamera.write(180-valCAM);
motorleft.write(valRUP+(valLLR-90));
motorright.write(valRUP-(valLLR-90));

conDOL = constrain(conDOL,0, 180);
conDOL=conDOL+(90-varDOL)/4;
motordol.write(conDOL);

conGOR = constrain(conGOR,0, 180);
conGOR=conGOR+(90-varGOR)/4;
motorgora.write(conGOR);

conPRA = constrain(conPRA,0, 180);
conPRA=conPRA+(90-varPRA)/4;
motorprawo.write(conPRA);

conLEW = constrain(conLEW,0, 180);
conLEW=conLEW+(90-varLEW)/4;
motorlewo.write(conLEW);


Serial.print(" left : ");
Serial.print(valRUP+(valLLR-90));
Serial.print(" right : ");
Serial.print(valRUP-(valLLR-90));
Serial.print(" front : ");
Serial.print(180-valLUP);
Serial.print(" camera : ");
Serial.print(180-valCAM);
Serial.print(" dol : ");
Serial.print(conDOL);
Serial.print(" gora : ");
Serial.print(conGOR);
Serial.print(" prawo : ");
Serial.print(conPRA);
Serial.print(" lewo : ");
Serial.println(conLEW);

//delay(3000);
}

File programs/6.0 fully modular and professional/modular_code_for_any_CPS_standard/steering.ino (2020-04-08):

#define motorupdownPIN 12
#define motorsidePIN 6
#define motorleftPIN 8
#define motorrightPIN 9

Servo motorupdown;
Servo motorside;
Servo motorleft;
Servo motorright;

int valLUP;
int valRUP;
int valLLR;
int valRLR;


void steer(){
      motorupdown.attach(motorupdownPIN,1000,2000);
      motorside.attach(motorsidePIN,1000,2000);
      motorleft.attach(motorleftPIN,1000,2000);
      motorright.attach(motorrightPIN,1000,2000);

      valLLR = map(ch[4], 1000, 2000, 0, 180);
      valRUP = map(ch[2], 1000, 2000, 0, 180);
      valLUP = map(ch[3], 1000, 2000, 0, 180);
      valRLR = map(ch[1], 1000, 2000, 0, 180);

      motorupdown.write(180-valLUP+38);
      motorside.write(valRLR);
      motorleft.write(valRUP+(valLLR-90)+38);
      motorright.write(valRUP-(valLLR-90)+34);


  printmotors();

}



void printmotors(){
  Serial.print("motor updown:");
  Serial.print(analogRead(motorupdownPIN));
  Serial.print("\t");
  Serial.print("motor side:");
  Serial.print(analogRead(motorsidePIN));
  Serial.print("\t");
  Serial.print("motor left:");
  Serial.print(analogRead(motorleftPIN));
  Serial.print("\t");
  Serial.print("motor right:");
  Serial.println(analogRead(motorrightPIN));
  delay(000);
}

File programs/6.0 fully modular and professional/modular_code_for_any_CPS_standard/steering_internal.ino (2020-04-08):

Servo motorcamera;
#define camerapin 5
int varCAM;
int conCAM;

float valbat;
float volt;

#define ledlights 6
float vallights;
int osdlights;
float conLIGHT;
/*int ledPinGreen = 9;
int ledPinRed = 11;*/



void internalStart(){
  ledStart();
  //thermometerStart();
}

void ledStart(){
  /*pinMode(ledPinGreen, OUTPUT);
  pinMode(ledPinRed, OUTPUT);*/
  pinMode(ledlights, OUTPUT);
  
  for (int fadeValue = 0 ; fadeValue <= 255; fadeValue += 1) {
  /*analogWrite(ledPinGreen, fadeValue);
  analogWrite(ledPinRed, fadeValue);*/
  analogWrite(ledlights, fadeValue);
  delay(10);
  }
}





void steerint(){
  //readbat();
  steercamera();
  //steerlights();
  //thermometerRun();
}

void readbat(){
  /*valbat=analogRead(A2);
  volt = valbat * 5.0/1023;*/
  /*osd.printMax7456Char(0x90,4,1,false,false);
  osd.print("100",0,1,false,true);
  osd.printMax7456Char(0x81,3,1,false,true);
  osd.print("12.6V",0,2,false,true);*/
}

void steercamera(){
    motorcamera.attach(camerapin, 500, 2500);
    varCAM = map(ch[5], 1000, 2000, 0, 180);

    conCAM = constrain(conCAM, 0, 180);
    conCAM=conCAM+(90-varCAM)/64;
    motorcamera.write(conCAM);

    /*osd.print("cam", 0, 15);

    if(conCAM>178){
      osd.printMax7456Char(0xB7, 4, 15);
    }else if(conCAM>148){
      osd.printMax7456Char(0xB8, 4, 15);
    }else if(conCAM>118){
      osd.printMax7456Char(0xB9, 4, 15);
    }else if(conCAM>92){
      osd.printMax7456Char(0xBA, 4, 15);
    }else if(conCAM<=92 && conCAM>=88){
      osd.printMax7456Char(0xBB, 4, 15);
    }else if(conCAM>62){
      osd.printMax7456Char(0xBC, 4, 15);
    }else if(conCAM>32){
      osd.printMax7456Char(0xBD, 4, 15);
    }else if(conCAM>2){
      osd.printMax7456Char(0xBE, 4, 15);
    }else if(conCAM<=2){
      osd.printMax7456Char(0xBF, 4, 15);
    }*/

    printcamera();
}

void printcamera(){
    Serial.print("camera: ");
    Serial.print(conCAM);
    Serial.print("\t");
    Serial.println(analogRead(camerapin));
    delay(000);
}






void steerlights(){
  vallights = map(ch[8], 1000, 2000, 0, 255);

  conLIGHT=conLIGHT+(vallights-conLIGHT)/30;

if(conLIGHT>1){
  analogWrite(ledlights,conLIGHT);
}else{
  analogWrite(ledlights,0);
}

/*if(conLIGHT>200){
  osd.printMax7456Char(0xF6, 27, 1);
  osd.printMax7456Char(0xF5, 26, 1);
}else if(conLIGHT>100){
  osd.printMax7456Char(0xF6, 27, 1);
  osd.printMax7456Char(0x00, 26, 1);
}else{
  osd.printMax7456Char(0x00, 27, 1);
  osd.printMax7456Char(0x00, 26, 1);
}*/

  //printlights();
}




void printlights(){
  Serial.print("lights:");
  Serial.print("\t");
  Serial.print(conLIGHT);
  Serial.print("\t");
  Serial.println(analogRead(ledlights));
  delay(000);
}

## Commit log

2020-01-14 go fuck yourself
    [motorek.stl]
2020-01-14 on a tree
    [Body1.stl]
2020-01-14 added manipulator stls
    [częśćruchoma_trzymaka.stl, częśćruchoma_trzymaka_dobridga.stl, przyciskacz_trzymaka.stl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]
2020-01-14 deleted crap
    [częśćruchoma_trzymaka.stl, częśćruchoma_trzymaka_dobridga.stl, przyciskacz_trzymaka.stl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]
2020-01-15 programs organization
    [C3.csv, C3.xlsx, CE3_Case_scaled_fixed.stl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]
2020-05-22 added ESC files in the PCB folder
    [The electronic speed controller schematic.brd, The electronic speed controller schematic.sch]
2020-05-22 changed a folder name cuz FILIP didn't like it
    [The electronic speed controller schematic.brd, The electronic speed controller schematic.sch]
2020-05-28 fixed stuff for poitrek
    [main.cpp]

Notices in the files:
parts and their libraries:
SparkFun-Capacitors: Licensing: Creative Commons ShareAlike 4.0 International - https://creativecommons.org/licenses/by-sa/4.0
